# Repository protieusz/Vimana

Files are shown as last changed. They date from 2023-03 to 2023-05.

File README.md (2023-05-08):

# Vimana
A 40% Handwired Column Staggered Keeb with a 35mm Meshi Trackball Module in the middle in a shape of a Vimana.

What is a Vimana? As per https://en.wikipedia.org/wiki/Vimana, it is the following: 
"Vimāna are mythological flying palaces or chariots described in Hindu texts and Sanskrit epics. The "Pushpaka Vimana" of Ravana (who took it from Kubera; Rama returned it to Kubera) is the most quoted example of a vimana. Vimanas are also mentioned in Jain texts."

This is my interpretation of the Vimana keeb layout. BEHOLD!!! The VIMANA!

PCB version is untested and the bottom plate center Meshi trackball screw holes are off when tested during handwiring. Someone will need to use a digital caliper to fine tune the screw holes measurement.

Vimana Handwire Prototype Final


Ghetto bottom plate that needs screw adjustment. Hmm maybe the pcb bottom plate might need adjusting also


Handwiring
A5AA64C3-315C-4580-A2B7-2B00164D9C0D_1_105_c

Handwiring the integrated Meshi Trackball module...the main prize

EDA0FA89-386A-4CFB-8EF6-7116BE1918E7

PCB Rev 1.0 Ready For Print.




Switch plate for pcb



Back plate for pcb



Meshi Trackball Module




Prototype



Key layout

vimanar2

Revised version 2.0 integrated switch plate case for handwiring



Revised version 2.0. Right Half done....waiting for other half to be printed





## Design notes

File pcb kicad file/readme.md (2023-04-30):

The pcb file is converted from EasyEDA json file so I don't know how well it would work with KiCad.

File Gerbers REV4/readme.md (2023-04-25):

The PCB Gerber files have not been tested nor been printed yet.  Due to budget constraints, I will not be printing them. The PCB design was created in EasyEDA and auto routing has been used.  There were no DRC errors. MCU required will be Elite C or Pro Micro but you have to double check the pins since I didn't check for PM when I initially design it.  The reason of using PM based mcu is because the Meshi Trackball module needs 5V to function and if your use RP2040 and hook it up to VBUS or 5v, in the long run the feedback will kill the mcu eventually unless you know how to use the level shifter.

The gerbers are free for you guys to modify and print but be warn, print at your own risk and I don't accept any responsibilities. The same goes with switch plate and backplate.  No gurantee that they will fit. No support will be given. Have fun and good luck.

List of Supplies needed for build:

`-` Elite-C mcu

`-` SMD diode 0805 SOD-123

`-` 26AWG tinned single core copper wires

`-` Aki's Meshi trackball modul

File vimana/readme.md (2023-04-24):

QMK source code is updated to QMK 0.19.  

Trackball movements, mouse button 1 & 2 and scroll lock all works.

The only thing I have not got it working is the OLED display. I have to find time to fix it or someone can help fix it.

I will provide both the source code and the hex file to this repository.

Enjoy and good luck!

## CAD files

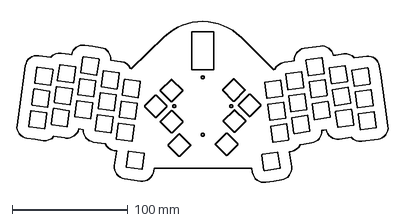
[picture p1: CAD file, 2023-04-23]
STLs/Vimanawholebottomrefinewithholes.dxf
321.5 x 143.8 mm

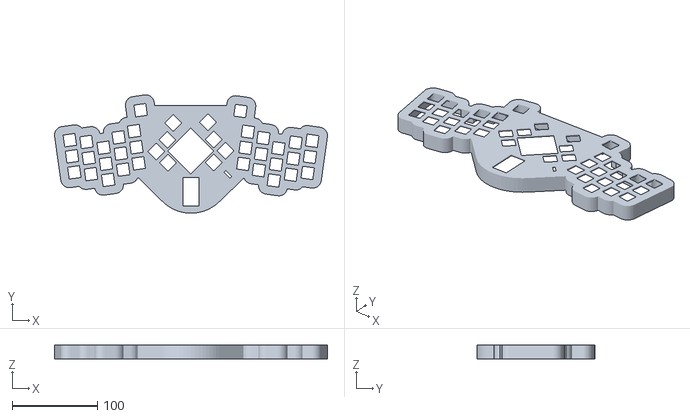
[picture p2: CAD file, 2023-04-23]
STLs/VimanaR2Wholebodyswitch.stl
320.1 x 138.9 x 16.5

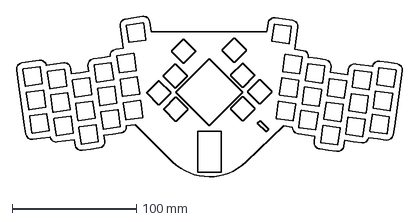
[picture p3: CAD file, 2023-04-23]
STLs/VimanaR2pcbNooffsetSwitch.dxf
310.8 x 133.1 mm

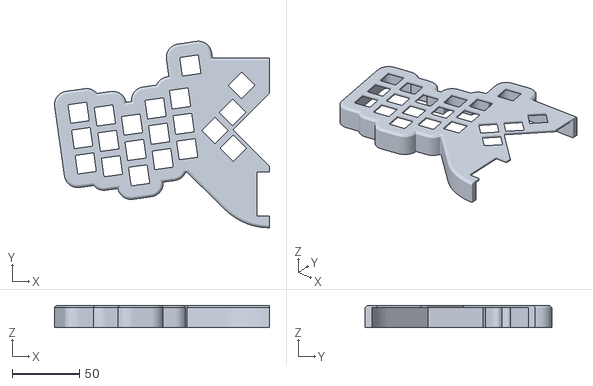
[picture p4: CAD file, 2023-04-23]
STLs/VimanaR2RIGHTSwitchbodyChamfer.stl
160.0 x 138.9 x 16.5

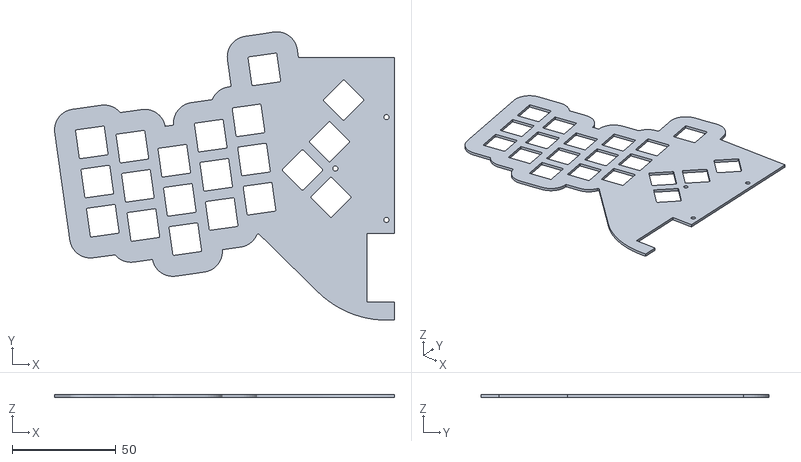
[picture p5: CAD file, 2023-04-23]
STLs/VimanaRIGHTBottomRefined.stl
163.7 x 138.9 x 1.50

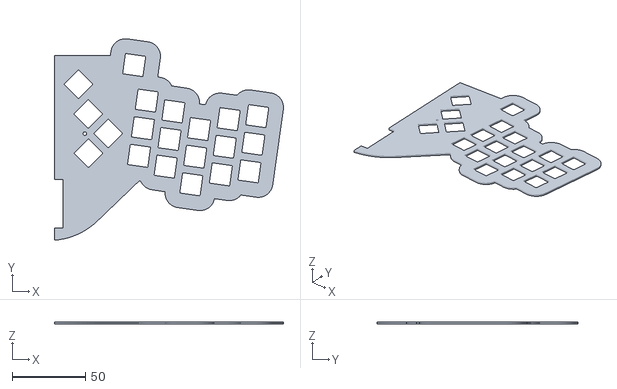
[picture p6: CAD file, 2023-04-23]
STLs/VimanaLEFTBottomRefined.stl
156.5 x 137.6 x 1.50

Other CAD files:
STLs/VimanaR2LEFTSwitchbodyChamfer.stl

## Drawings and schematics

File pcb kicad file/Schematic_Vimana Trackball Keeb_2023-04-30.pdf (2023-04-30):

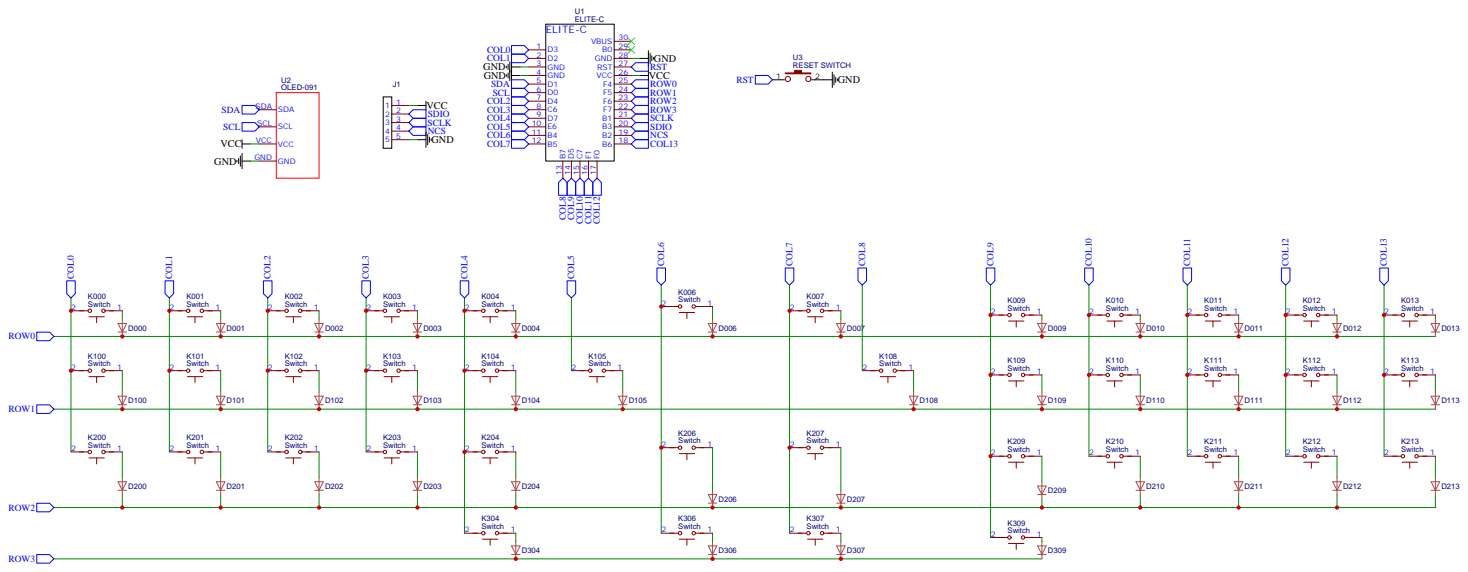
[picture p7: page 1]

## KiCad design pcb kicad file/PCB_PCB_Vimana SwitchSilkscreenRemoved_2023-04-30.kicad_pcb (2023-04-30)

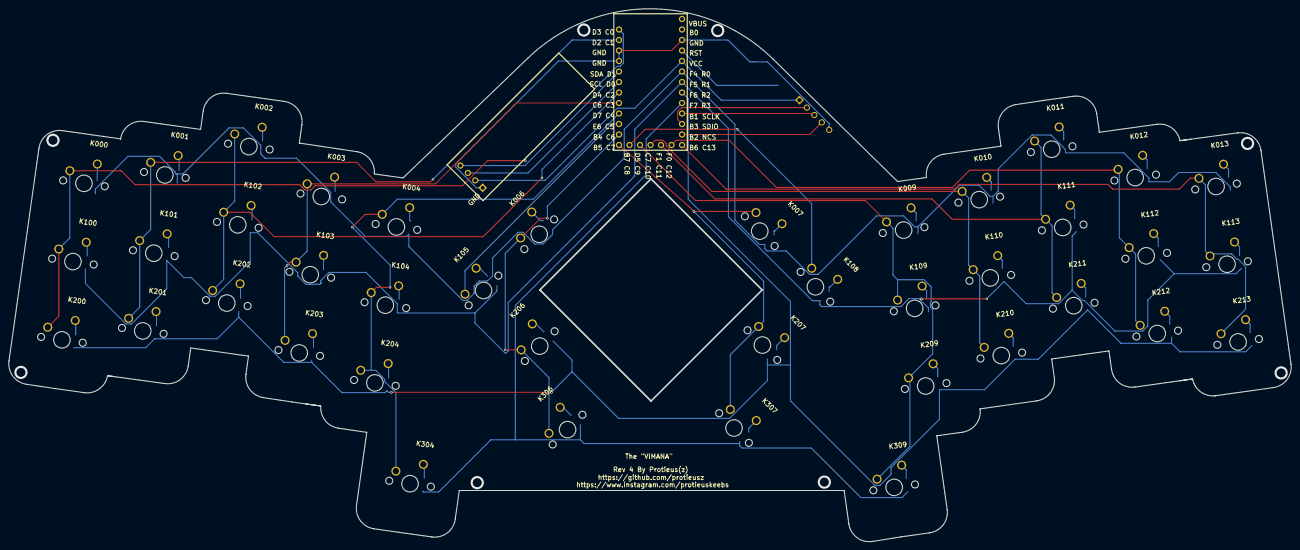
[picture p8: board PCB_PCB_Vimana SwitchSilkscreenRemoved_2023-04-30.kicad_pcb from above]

Board: 2 copper layers, 310.2 x 128.9 mm, 84 parts (0 on the bottom side), 66 nets.

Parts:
D000, D001, D002, D003, D004, D006, D007, D009, D010, D011, D012, D013, D100, D101, D102, D103, D104, D105, D108, D109, D110, D111, D112, D113, D200, D201, D202, D203, D204, D206, D207, D209, D210, D211, D212, D213, D304, D306, D307, D309: DIODE-SOD123
J1: 5-Pin Male Header, 2.54mm Pitch, Thru-hole, squar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; 5-PIN_MALE_HEADER,_2.54MM_PITCH,_1.016MM_HOLE
K000, K001, K002, K003, K004, K006, K007, K009, K010, K011, K012, K013, K100, K101, K102, K103, K104, K105, K108, K109, K110, K111, K112, K113, K200, K201, K202, K203, K204, K206, K207, K209, K210, K211, K212, K213, K304, K306, K307, K309: 100; CHERRY_MX_100_MILLMAX
U1: ELITE-C
U2: OLED-091
U3: RESET SWITCH

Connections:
COL0: K000.2, K100.2, K200.2, U1.1
COL1: K001.2, K101.2, K201.2, U1.2
COL2: K002.2, K102.2, K202.2, U1.7
COL3: K003.2, K103.2, K203.2, U1.8
COL4: K004.2, K104.2, K204.2, K304.2, U1.9
COL5: K105.2, U1.10
COL6: K006.2, K206.2, K306.2, U1.11
COL7: K007.2, K207.2, K307.2, U1.12
COL8: K108.2, U1.13
COL9: K009.2, K109.2, K209.2, K309.2, U1.14
COL10: K010.2, K110.2, K210.2, U1.15
COL11: K011.2, K111.2, K211.2, U1.16
COL12: K012.2, K112.2, K212.2, U1.17
COL13: K013.2, K113.2, K213.2, U1.18
D001_A: D001.A, K001.1
D002_A: D002.A, K002.1
D004_A: D004.A, K004.1
D006_A: D006.A, K006.1
D007_A: D007.A, K007.1
D010_A: D010.A, K010.1
D012_A: D012.A, K012.1
D013_A: D013.A, K013.1
D100_A: D100.A, K100.1
D103_A: D103.A, K103.1
D105_A: D105.A, K105.1
D108_A: D108.A, K108.1
D109_A: D109.A, K109.1
D111_A: D111.A, K111.1
D113_A: D113.A, K113.1
D200_A: D200.A, K200.1
D203_A: D203.A, K203.1
D206_A: D206.A, K206.1
D207_A: D207.A, K207.1
D211_A: D211.A, K211.1
D213_A: D213.A, K213.1
D304_A: D304.A, K304.1
D306_A: D306.A, K306.1
D307_A: D307.A, K307.1
D309_A: D309.A, K309.1
GND: J1.5, U1.3, U1.4, U1.28, U2.GND, U3.2
K000_1: D000.A, K000.1
K003_1: D003.A, K003.1
K009_1: D009.A, K009.1
K011_1: D011.A, K011.1
K101_1: D101.A, K101.1
K102_1: D102.A, K102.1
K104_1: D104.A, K104.1
K110_1: D110.A, K110.1
K112_1: D112.A, K112.1
K201_1: D201.A, K201.1
K202_1: D202.A, K202.1
K204_1: D204.A, K204.1
K209_1: D209.A, K209.1
K210_1: D210.A, K210.1
K212_1: D212.A, K212.1
NCS: J1.4, U1.19
ROW0: D000.C, D001.C, D002.C, D003.C, D004.C, D006.C, D007.C, D009.C, D010.C, D011.C, D012.C, D013.C, U1.25
ROW1: D100.C, D101.C, D102.C, D103.C, D104.C, D105.C, D108.C, D109.C, D110.C, D111.C, D112.C, D113.C, U1.24
ROW2: D200.C, D201.C, D202.C, D203.C, D204.C, D206.C, D207.C, D209.C, D210.C, D211.C, D212.C, D213.C, U1.23
ROW3: D304.C, D306.C, D307.C, D309.C, U1.22
RST: U1.27, U3.1
SCL: U1.6, U2.SCL
SCLK: J1.3, U1.21
SDA: U1.5, U2.SDA
SDIO: J1.2, U1.20
VCC: J1.1, U1.26, U2.VCC

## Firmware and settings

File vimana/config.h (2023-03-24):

#pragma once

#include "config_common.h"

/* key matrix size */
#define MATRIX_ROWS 4
#define MATRIX_COLS 14

/* Set 0 if debouncing isn't needed */
#define DEBOUNCE 5

/* POINTING_DEVICE */
#define ADNS5050_SCLK_PIN         B1
#define ADNS5050_SDIO_PIN         B2
#define ADNS5050_CS_PIN           B3

#define POINTING_DEVICE_ROTATION_180

/* OLED */
#define OLED_FONT_H "keyboards/protieus/vimana/lib/glcdfont.c"

#ifdef COMBO_ENABLE
#    define COMBO_COUNT 6
#    define COMBO_TERM 200
#endif

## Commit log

2023-03-24 screw up the files...uploading new one
2023-03-24 Added case pic and key layout
2023-04-13 Add pcb rev 1 pic
2023-04-14 Add switch and backplate pics
2023-04-14 Add more pcb colors
2023-04-23 Add 3D STL files for handwire and pcb base design
    [VimanaLEFTBottomRefined.stl, VimanaR2LEFTSwitchbodyChamfer.stl, VimanaR2RIGHTSwitchbodyChamfer.stl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]
2023-04-23 Add Untested Rev4 Gerber pcb and plates
2023-04-30 Add bottom plate pic
2023-04-30 pcb kicad file for Vimana for editing
    [PCB_PCB_Vimana SwitchSilkscreenRemoved_2023-04-30.kicad_pcb]
2023-04-30 Schematic file added
2023-05-08 Screw holes update.
